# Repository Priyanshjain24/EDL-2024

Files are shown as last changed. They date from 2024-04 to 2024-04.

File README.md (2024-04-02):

# EDL-2024

EasyEDA PCB Project - https://easyeda.com/editor#id=|2c9fe7a39e5e4bcda1221276535b3dad|aed5360678bb4e42a727d4c10888fd0d*

Project Documentation - https://docs.google.com/document/d/11eXPvF9VfRDBCwMDT-JqijSKkcDsmX2YW28t79alUM8/edit?usp=sharing

GitHub - https://github.com/Priyanshjain24/EDL-2024/

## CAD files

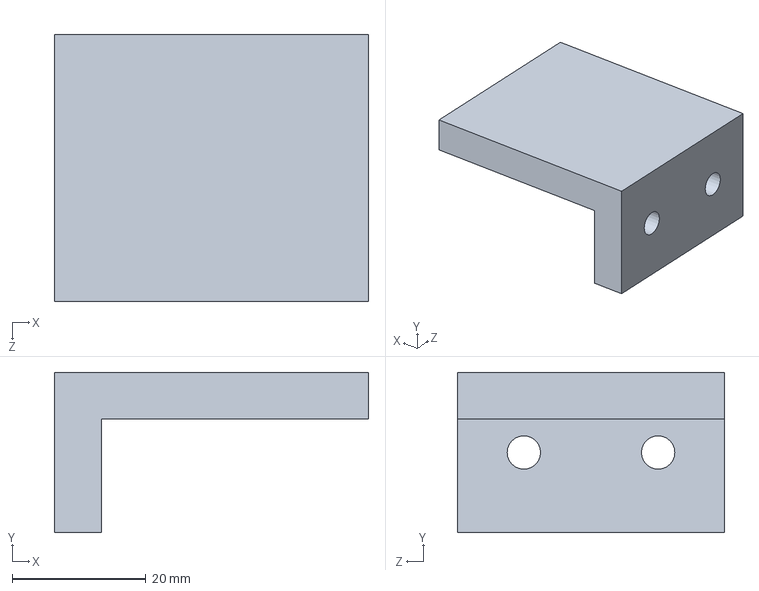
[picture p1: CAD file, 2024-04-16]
CAD_Files/Camera_Mount/arm-rest.SLDPRT
47.0 x 24.0 x 40.0 mm

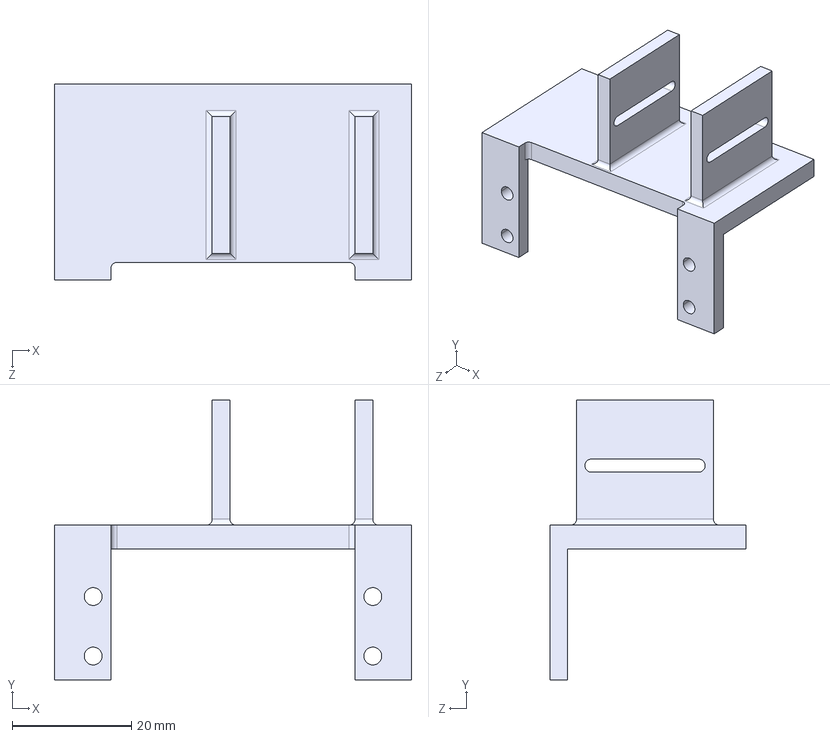
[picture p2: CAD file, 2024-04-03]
CAD_Files/Camera_Mount/Camear_Mount.STEP
60.0 x 47.0 x 33.0 mm

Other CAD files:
CAD_Files/Camera_Mount/Camear_Mount.SLDPRT
CAD_Files/Camera_Mount/Camear_Mount.STL
CAD_Files/Camera_Mount/arm-rest.STL

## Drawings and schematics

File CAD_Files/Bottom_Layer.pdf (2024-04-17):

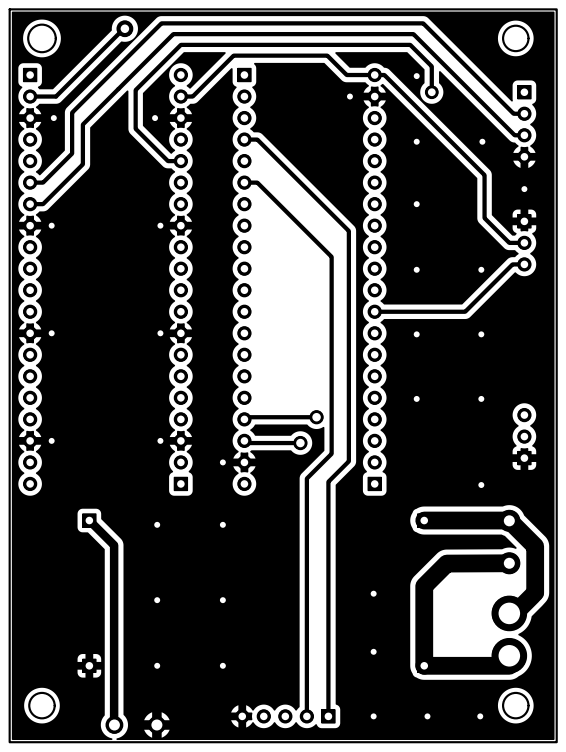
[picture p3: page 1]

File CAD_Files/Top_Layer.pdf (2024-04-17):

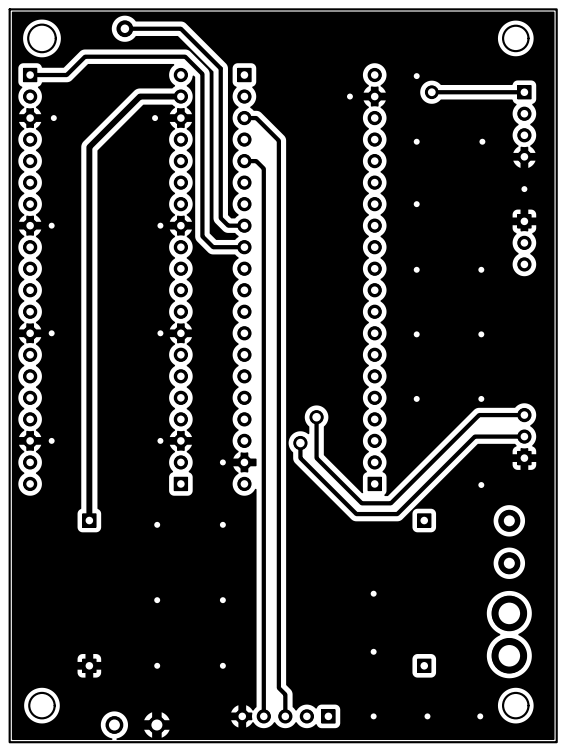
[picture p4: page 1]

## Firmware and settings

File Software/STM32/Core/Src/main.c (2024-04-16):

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
/* Includes ------------------------------------------------------------------*/
#include "main.h"

/* USER CODE BEGIN Includes */
#include "stdio.h"
#include "FS-iA6B.h"
#include <string.h>
/* USER CODE END Includes */

TIM_HandleTypeDef htim1;

UART_HandleTypeDef huart6;

/* USER CODE BEGIN PV */
extern uint8_t ibus_rx_buf[32];
extern uint8_t ibus_rx_cplt_flag;
uint16_t rxValues[8];

uint16_t LED;
int32_t dutyL, dutyR;
int16_t speed, speedL, speedR, steering, mode;
uint16_t CounterPeriod = 7200;
int16_t direction = 0;
int16_t directionL = 0;
int16_t directionR = 0;

uint16_t smoothing, smoothing1;
uint16_t smoothingPrev= 1500;
uint16_t smoothingPrev1 = 1500;

uint16_t window_size = 10;
uint16_t window_index = 0;
int32_t window[10];
int32_t movingSum = 0;
int32_t past = 0;

int k = 450;

int initial = 0;
/* USER CODE END PV */

void SystemClock_Config(void);
static void MX_GPIO_Init(void);
static void MX_USART2_UART_Init(void);
static void MX_USART6_UART_Init(void);
static void MX_TIM1_Init(void);
/**
  * @brief  The application entry point.
  * @retval int
  */
int main(void)
{
  /* MCU Configuration--------------------------------------------------------*/

  /* Reset of all peripherals, Initializes the Flash interface and the Systick. */
  HAL_Init();

  /* Configure the system clock */
  SystemClock_Config();

  /* Initialize all configured peripherals */
  MX_GPIO_Init();
  MX_USART2_UART_Init();
  MX_USART6_UART_Init();
  MX_TIM1_Init();
  /* USER CODE BEGIN 2 */
  LL_USART_EnableIT_RXNE(USART2);
  LL_USART_EnableIT_RXNE(USART6);


  HAL_TIM_PWM_Start(&htim1, TIM_CHANNEL_1);   // Output PWM Generation
  HAL_TIM_PWM_Start(&htim1, TIM_CHANNEL_2);   // Output PWM Generation

  /* USER CODE END 2 */

  /* Infinite loop */
  /* USER CODE BEGIN WHILE */

  while (1)
  {
//	  if(initial == 0){
//		  HAL_Delay(3000);
//		  initial = 1;
//	  }

    /* USER CODE END WHILE */

    /* USER CODE BEGIN 3 */


	  if(ibus_rx_cplt_flag == 1)
	  {
		  ibus_rx_cplt_flag = 0;
		  if(iBus_Check_CHKSUM(&ibus_rx_buf[0], 32) == 1)
		  {
		  	  HAL_GPIO_TogglePin(GPIOC, GPIO_PIN_13);
			  	rxValues[0] = (ibus_rx_buf[2] | ibus_rx_buf[3]<<8);
			  	rxValues[1] = (ibus_rx_buf[4] | ibus_rx_buf[5]<<8);
			  	rxValues[2] = (ibus_rx_buf[6] | ibus_rx_buf[7]<<8);
			  	rxValues[3] = (ibus_rx_buf[8] | ibus_rx_buf[9]<<8);
			  	rxValues[4] = (ibus_rx_buf[10] | ibus_rx_buf[11]<<8);
			  	rxValues[5] = (ibus_rx_buf[12] | ibus_rx_buf[13]<<8);
			  	rxValues[6] = (ibus_rx_buf[14] | ibus_rx_buf[15]<<8);
			  	rxValues[7] = (ibus_rx_buf[18] | ibus_rx_buf[19]<<8);

//			  	if(!((1000 <= rxValues[0] && rxValues[0] <= 2000)&&
//			  			(1000 <= rxValues[1] && rxValues[1] <= 2000)&&
//						(1000 <= rxValues[2] && rxValues[2] <= 2000)&&
//						(1000 <= rxValues[3] && rxValues[3] <= 2000)&&
//						(1000 <= rxValues[4] && rxValues[4] <= 2000)&&
//						(1000 <= rxValues[5] && rxValues[5] <= 2000)&&
//						(1000 <= rxValues[6] && rxValues[6] <= 2000)&&
//						(1000 <= rxValues[7] && rxValues[7] <= 2000)))
//			  	{continue;}

			  	if(rxValues[7] < 1500){HAL_UART_Transmit(&huart6, ibus_rx_buf, 32, 100);}


		  }

	  }

	  if(rxValues[6] > 1500){ LED = 1;}
	  else {LED = 0;}
	  HAL_GPIO_WritePin(GPIOB, GPIO_PIN_9, LED);

	  if(rxValues[7] < 1500){continue;}

	  speed = rxValues[2];
	  steering = rxValues[0];


//	  window[window_index] = speed;
//	  for (uint16_t i = 0; i < window_size; i++){
//		  movingSum += window[i];
//	  }
//
//	  movingSum = movingSum/window_size;
//	  window_index = (window_index + 1)%window_size;
//	  speed = movingSum;

	  //smoothing
	  smoothing = speed*0.20 + smoothingPrev*0.80;
	  smoothingPrev = smoothing;
	  speed = smoothing;

	  smoothing1 = steering*0.20 + smoothingPrev1*0.80;
	  smoothingPrev1 = smoothing1;
	  steering = smoothing1;
//
	  speed = speed - 1500;
	  steering = steering - 1500;
	  if (speed > -50 && speed < 50){speed = 0;}
	  if (steering > -50 && steering < 50){steering = 0;}
//
//	  if (steering == 0){
//		  direction = 0;
//		  if(speed < 0){
//			  direction = 1;
//			  speed = speed*-1;
//		  }
//		  speedL = speed;
//		  speedR = speed;
//		  directionR = direction;
//		  directionL = !direction;
//	  }
//	  else if (steering != 0 && speed == 0){
//		  direction = 0;
//		  if(steering < 0){
//			  direction = 1;
//			  steering = steering*-1;
//		  }
//		  speedL = steering;
//		  speedR = steering;
//		  directionR = direction;
//		  directionL = direction;
//
//	  }
//	  else {
//		  direction = 0;
//		  if(speed < 0){
//			  direction = 1;
//			  speed = speed*-1;
//		  }
//
//
//		  if(steering < 0){
//			  speedL = speed - (int16_t)(speed*steering/500);
//			  speedR = speed + (int16_t)(speed*steering/500);
//		  }
//		  else{
//			  speedL = speed + (int16_t)(speed*steering/500);
//			  speedR = speed - (int16_t)(speed*steering/500);
//		  }
//w
//		  directionR = direction;
//		  directionL = !direction;

		  ////////////////////////////////////////////////

		  directionL = 0;
		  directionR = 0;



		  speedL = speed - (int16_t)(k*steering/500);
		  speedR = speed + (int16_t)(k*steering/500);


		  if(speedL < 0){
			  directionL = 1;
			  speedL = speedL*-1;
		  }
		  if(speedR < 0){
			  directionR = 1;
			  speedR = speedR*-1;
		  }




	  dutyL = (uint16_t) ((speedL*CounterPeriod)/(500 + k));
	  dutyR = (uint16_t) ((speedR*CounterPeriod)/(500 + k));
	  TIM1->CCR1 = dutyL;
	  TIM1->CCR2 = dutyR;
	  HAL_GPIO_WritePin(GPIOB, GPIO_PIN_14, directionL);
	  HAL_GPIO_WritePin(GPIOB, GPIO_PIN_15, directionR);


//	  HAL_Delay(10);
  }
  /* USER CODE END 3 */
}

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
/* USER CODE BEGIN 4 */
uint8_t bytesTransd = 0;
uint8_t txcount = 0;
uint8_t startPosition = 0;


/* USER CODE END 4 */
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


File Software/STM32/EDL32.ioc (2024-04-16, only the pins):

Mcu.UserName=STM32F401CCUx
PA11.Signal=USART6_TX
PA12.Signal=USART6_RX
PA13.Signal=SYS_JTMS-SWDIO
PA14.Signal=SYS_JTCK-SWCLK
PA2.Signal=USART2_TX
PA3.Signal=USART2_RX
PA8.Signal=S_TIM1_CH1
PA9.Signal=S_TIM1_CH2
PB14.Signal=GPIO_Output
PB15.Signal=GPIO_Output
PB3.Signal=SYS_JTDO-SWO
PB9.Signal=GPIO_Output
PC13-ANTI_TAMP.Signal=GPIO_Output

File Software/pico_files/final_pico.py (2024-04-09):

from machine import I2C, Pin, UART
import utime
import ustruct
import sys
import time
from math import atan2, acos, sin, cos, asin, sqrt, atan
from math import pi as PI

RADIAN_TO_DEGREE = 180 / PI
DEGREE_TO_RADIAN = PI / 180
DISPLACEMENT_SCALE = 3
BASE_SPEED_SCALE_R = 15
BASE_SPEED_SCALE_L = 8

l1 = 10.5
l2 = 14.7

############################
pca9685_addr = 0x40
channel0 = 0x06
#Vcc of servo driver goes to 3v3 of pico(Pin36)
#Gnd of servo dirver goes to GND of pico(Pin38)
i2c = I2C(0,
            scl=Pin(5),
            sda=Pin(4),
            freq=400000)

uart = UART(0, baudrate=115200, tx=Pin(0), rx=Pin(1))
#GP0 and GP1 of pico == A12 and A11 of STM32
channels = 6
rxValues = [0]*channels
prev_rxValues = rxValues
loop_time = 0.0
##########3333333333333333
def clip(a, m, M):
    return min(max(a, m), M)

def process_stm_data(data, channels):
    """
    Each Channel give output in range (1000, 2000).
    2 bytes are recieved for each channel
    """
    list = [0]*channels
    
    list[0] = (data[2] | data[3]<<8)
    list[1] = (data[4] | data[5]<<8)
    list[2] = (data[6] | data[7]<<8)
    list[3] = (data[8] | data[9]<<8)
    list[4] = (data[10] | data[11]<<8)
    list[5] = (data[12] | data[13]<<8)

    
    for i in range(4):
        list[i] = (list[i] - 1500) / 500
    list[4] = (list[4] - 1000) / 500
    list[5] = (list[5] - 1000) / 500
    
    return list

class robotic_arm:
    def __init__(self, i2c = i2c, address = pca9685_addr, channel0 = channel0):
        self.i2c = i2c
        self.address = address
        self.channel0 = channel0
        self.write(0x00, 0x00)
        self.counts_in_one_cycle = 4096
        self.min_duty = 0.025
        self.max_duty = 0.125

    def write(self, register, data):
        msg = bytearray()
        msg.append(data)
        self.i2c.writeto_mem(self.address, register, msg)
        
    def read(self, register):
        msg = self.i2c.readfrom_mem(self.address, register, 1)[0]
        return msg
    
    def set_freq(self, freq):

        prescale = int(25000000.0 / 4096.0 / freq)
        old_mode = self.read(0x00) # Mode 1
    
        # print((old_mode & 0x7F) | 0x10)
        self.write(0x00, (old_mode & 0x7F) | 0x10) #sleep
        self.write(0xfe, prescale) # Prescale
        self.write(0x00, old_mode) # Mode 1
        time.sleep(0.001)
        self.write(0x00, old_mode | 0xa1)
        
    def pwm_gen(self, on, off, index):
    
        data = ustruct.pack('<HH', on, off)
        #print(data)
        self.i2c.writeto_mem(self.address, self.channel0 + 4 * index,  data)
    def set_joint_angle(self, joint_index, angle):
        #angle in degrees
        on = int(0)
        off = int(self.counts_in_one_cycle * (self.min_duty + (self.max_duty - self.min_duty) * angle / 180))
        #print(on, off, joint_index)
        self.pwm_gen(on = on, off = off, index = joint_index)

    def getXY(self, t1, t2):
        t1 = t1 * DEGREE_TO_RADIAN
        t2 = t2 * DEGREE_TO_RADIAN
        x = l1 * sin(t1) + l2 * sin(t1 + t2)
        y = l1 * cos(t1) + l2 * cos(t1 + t2)
        return x, y
    
    def getThetas(self, x, y):
        '''
        Solves IK for x and y 
        '''
        d2 = x**2 + y**2 
        a = (d2 - l1**2 - l2**2)/(2 * l1 * l2)
        a = clip(a, -1, 1)
        theta2 = acos(a)
        beta = atan2((l2 * sin(theta2)) , (l1 + l2 * cos(theta2)))
        theta1 = PI/2 - beta - atan2(y, x)
        theta1 = theta1 * RADIAN_TO_DEGREE
        theta2 = theta2 * RADIAN_TO_DEGREE
        return theta1, theta2

    def get_angles(self,rxValues):
        received_data = []
        for i in rxValues :
            received_data.append(180 * (i - 1000)/1000)    
        
        return received_data

if __name__ == '__main__':
    robotic_arm = robotic_arm()
    robotic_arm.set_freq(50)
    t_start = time.time()
    angle = 0
    store_delta = 0
    prev_t1, prev_t2 = None, None
    prev_angle_values = [None] * 6
    delta_angle = store_delta
    angle_values = [90]*6
    X,Y = [14.5, 10]
    X_req = X
    Y_req = Y
    theta1, theta2 = robotic_arm.getThetas(X, Y)
    angle_values[1] = theta1 + 39.34
    angle_values[2] = 142 - theta2
    angle_values[1] = clip(angle_values[1], 0, 180)
    angle_values[2] = clip(angle_values[2], 0, 180)
    while(1):
        #########
        if time.time() - t_start > 300:  
            print('Finished')
            break
        
        #########
        
        received_data = uart.read(32)
        if isinstance(received_data, bytes) != 1 or len(received_data) < channels :
            continue
        received_data = list(received_data)
        rxValues = process_stm_data(received_data, channels)
        deltaRx = sum([abs(rxValues[i] - prev_rxValues[i]) for i in range(4)])
        if deltaRx > 2 :
            rxValues = prev_rxValues
        prev_rxValues = rxValues
        print(f"{rxValues} Delta : {deltaRx}")
        #print("Received data:", rxValues)
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

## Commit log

2024-03-05 STM32 RX interface
2024-03-05 STM32 pico UART
2024-03-05 final pico file added
2024-03-12 motor output smoothing
2024-03-19 starter inverse kinematics
2024-03-19 inverse kinematics starter
2024-03-20 Working inverse kinematics
2024-04-02 moving in x-y direction in frame of camera-not working
    [final_pico.py]
2024-04-03 home position,+ve feedback due to fp error
    [final_pico.py]
2024-04-05 added LED code
2024-04-16 STM code
    [arm-rest.SLDPRT, arm-rest.STL]
2024-04-17 Create Readme
    This folder conits of PCB gerber files as well as PDF farmat files you can use either of two for PCB fabrication

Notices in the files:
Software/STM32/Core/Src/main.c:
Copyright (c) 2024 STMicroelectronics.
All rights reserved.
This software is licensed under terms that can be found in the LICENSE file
